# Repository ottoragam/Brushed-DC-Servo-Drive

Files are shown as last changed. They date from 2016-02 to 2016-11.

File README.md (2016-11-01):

# Brushed-DC-Servo-Drive
Low cost servo drive for small CNC machinery

##New version available on https://github.com/ottoragam/Tarocco

----------------------------------------------------------------------
Brushed DC Servo Drive (c) by Gino Magarotto

Brushed DC Servo Drive is licensed under a
Creative Commons Attribution-ShareAlike 3.0 Unported License.

You should have received a copy of the license along with this
work.  If not, see <http://creativecommons.org/licenses/by-sa/3.0/>.

----------------------------------------------------------------------
Low cost servo drive for small CNC machinery

Project log on https://hackaday.io/project/9433-brushed-dc-servo-drive

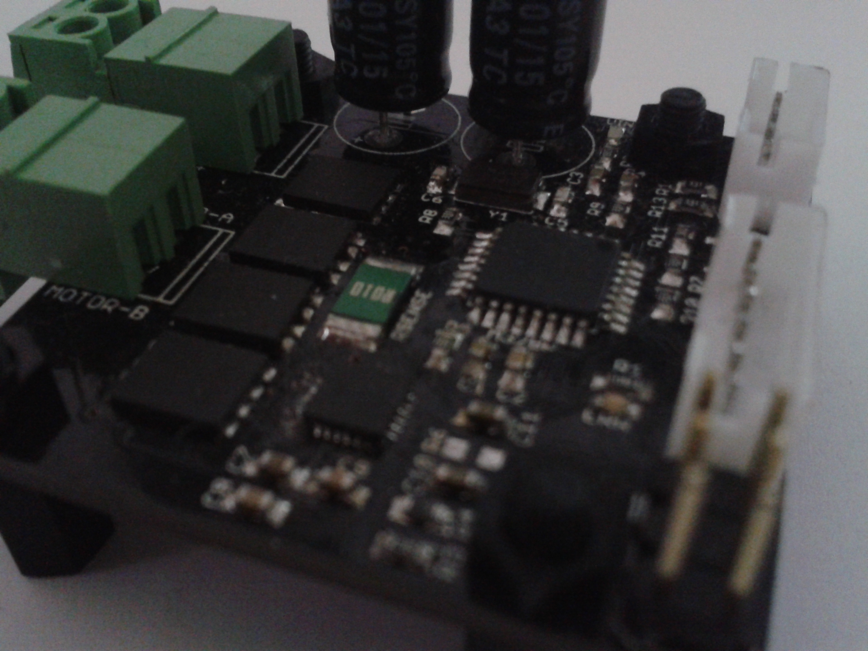
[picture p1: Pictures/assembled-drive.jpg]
drive


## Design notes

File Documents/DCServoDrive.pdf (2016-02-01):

# DC Servo Drive

Low cost closed loop controller for brushed DC motors.

# Safety Information

You should read this notes before installing this device.

CNC equipment can cause injuries due to the forces and momentum involved when the equipment is functioning. One may think that fingers and hands can be replaced with awesome robotic limbs, but they’re very time consuming to install and operate, so you better take care of your original parts.

This device is capable of operating up to 36 VDC and 7 A. The user needs to mind power supply polarity, as the device does not posses reverse polarity protection for any of the power inputs.

Be careful when close to the device while in operation, it may get very hot.

Disconnecting the motor from this device when powered is not advised, as it could damage it.

# Features

This device is designed to control brushed DC motors up to 36 V and 7 A ( HP) for ⅓ positioning in CNC machines such as routers, mills and 3D printers. It could also be used as the power stage of a mobile robot that requires odometry.

The device main components are:

## MCU for closed loop control

An ATmega328 microcontroller operating at 20 MHz is present to read the STEP/DIR signals from the machine controller, read a quadrature encoder input and perform the calculations required for PID control of the motor position.

It also controls an indicator LED for signaling the different fault modes the device is able to detect, such as motor overcurrent and driver undervoltage.

## MOSFET driver

A DRV8701 full bridge mosfet driver provides the capabilities to drive the MOSFET gates at an appropriate voltage with acceptable switching speed, while also protecting them from being damaged from heating due to insufficient gate voltage, shoot-through, etc.

The IC also provides a low side current sense amplifier that uses an external 10 mOhm power resistor to produce a voltage drop across it for the amplifier. The MCU reads the amplified voltage signal (gain is 20) easily with an 8-bit ADC.

Finally, the driver also performs a current limiting function to avoid damaging the transistors. The current level is set via two resistors in a voltage divider configuration.

## MOSFETs in H bridge configuration

The device utilizes four IRFH7545 MOSFETs. This transistors have a breakdown voltage of 60 V and a RDSon of 4.3 mOhm typically (or up to about 9.5 mOhm at 150 °C Tj) with a Vgs of 10 V.

# Device Characteristics

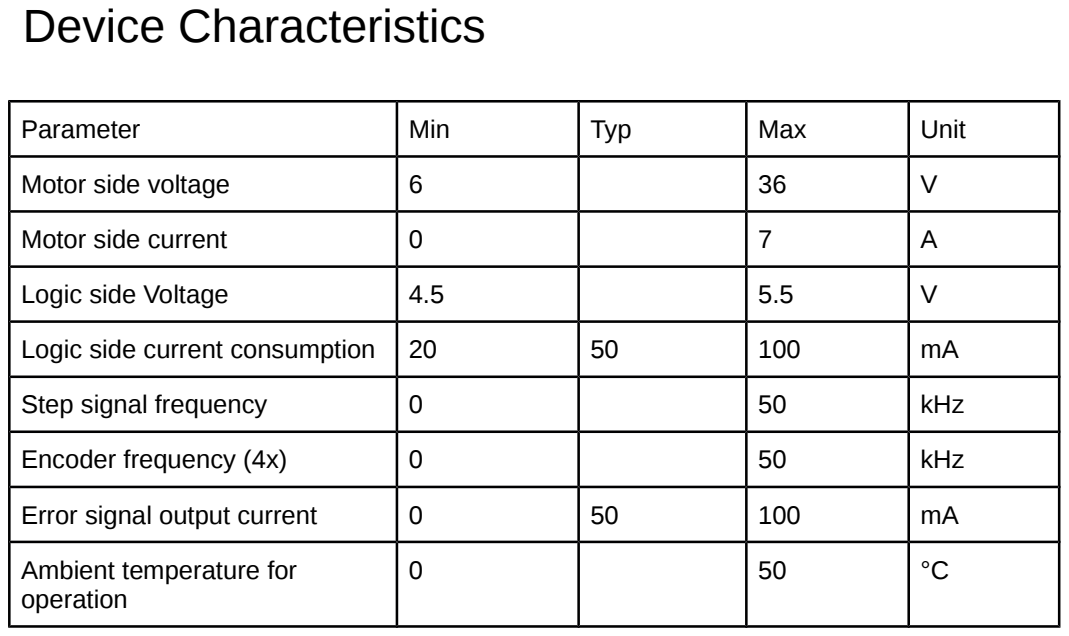
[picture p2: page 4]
Parameter; Min; Typ; Max; Unit; Motor side voltage; Motor side current; Logic side Voltage; Logic side current consumption 20; Step signal frequency; kHz; Encoder frequency (4x); Error signal output current

Ambient temperature for
operation

# Installation

The device comes with two pluggable terminals installed. The one marked with the MOTOR-A and MOTOR-B labels should be connected to the two cables for powering your motor. The other terminal, marked V+ and V- should be connected to a power supply of the correct voltage, ensuring the correct polarity of the connection.

Two JST PH headers are also installed on the board. the 4 way PH header accepts the encoder signal inputs and supplies 5 V to said encoder. The 6 way PH header is used for supplying 5 V to the board’s logic side, accepts the STEP, DIR and RESET signal from the machine controller and has the open drain ERROR output to inform the rest of the system of a fault condition.

The last connector present is a 3x2 0.1 in pitch male header. It is used for reprogramming the MCU present on the board.

Every microcontroller input present in the PH headers has a 330 Ohm resistor connected in series for protection against a mistake when making the connections or a misconfiguration of the pin in the case of a firmware change.

The input signals are active low.

Operation

Troubleshooting

Software Parameters

Electrical Schematic

Dimensional Drawing

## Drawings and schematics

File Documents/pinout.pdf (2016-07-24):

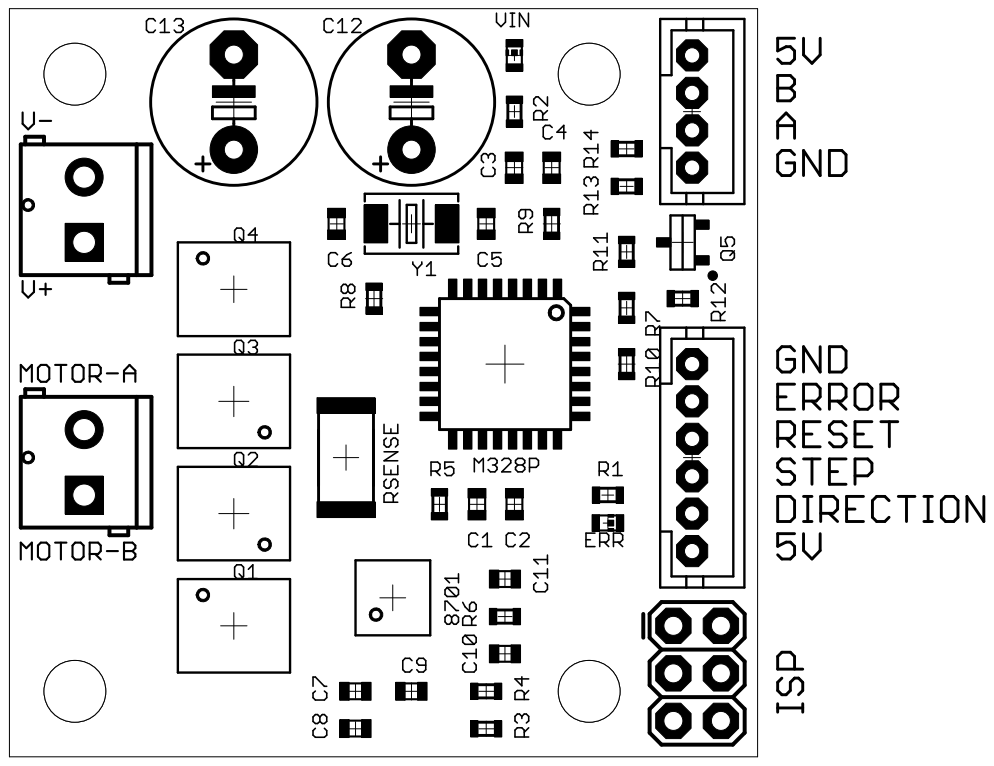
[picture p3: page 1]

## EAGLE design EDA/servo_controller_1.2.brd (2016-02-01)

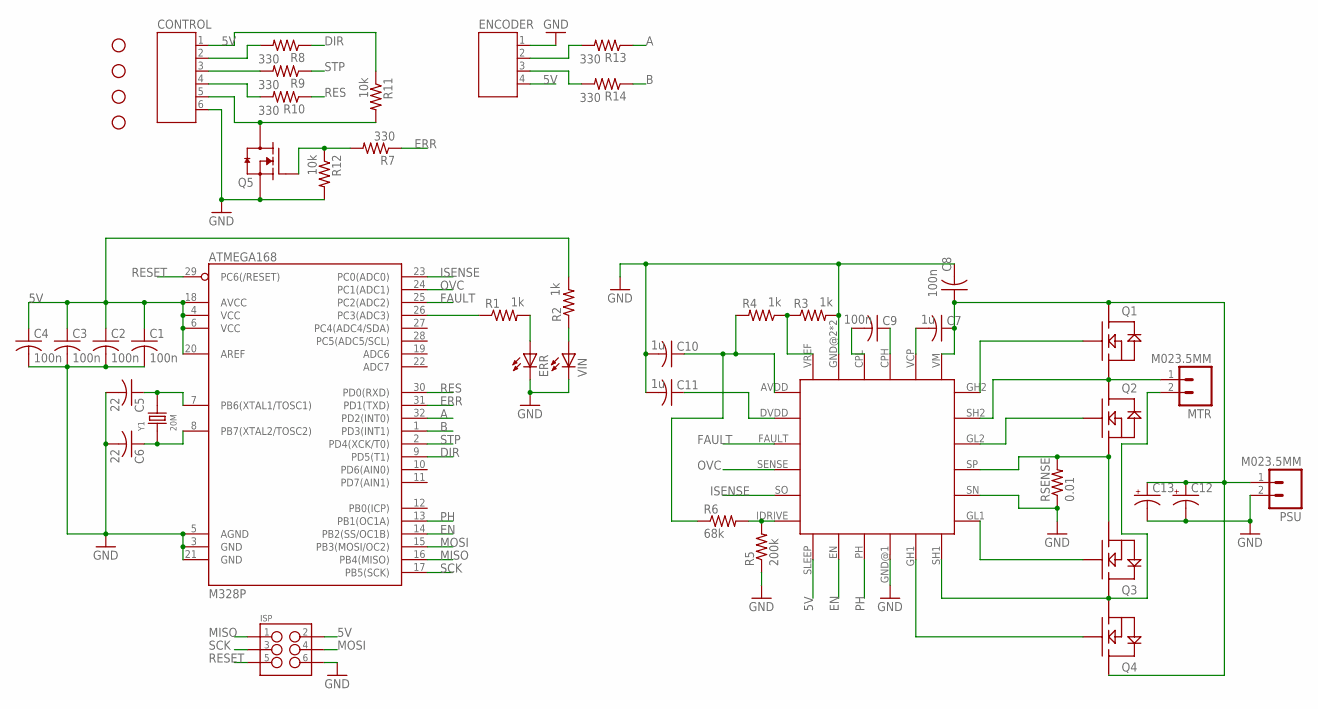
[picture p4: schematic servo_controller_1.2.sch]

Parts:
8701: DRV8701; VQFN24
C1, C2, C3, C4, C8, C9: 100n; C0603
C5, C6: 22; C0603
C7, C10, C11: 1u; C0603
C12, C13: CPOL-USE5-8.5; E5-8,5
CONTROL: JST-PH6
ENCODER: JST-PH4
ERR: LEDCHIP-LED0603; CHIP-LED0603
ISP: M03X22X3_SILK_SM; 2X3
M328P: ATMEGA168; TQFP32-08
MTR: M023.5MM; SCREWTERMINAL-3.5MM-2
PSU: M023.5MM; SCREWTERMINAL-3.5MM-2
Q1, Q2, Q3, Q4: NEXFET_SINGLECSD18537NQ5A; SON5X6
Q5: MOSFET-NCH_SOT-23; SOT95P280X135-3N
R1, R2, R3, R4: 1k; R0603
R5: 200k; R0603
R6: 68k; R0603
R7, R8, R9, R10, R13, R14: 330; R0603
R11, R12: 10k; R0603
RSENSE: 0.01; R2512
STANDOFF1, STANDOFF2, STANDOFF3, STANDOFF4: STAND-OFF
VIN: LEDCHIP-LED0603; CHIP-LED0603
Y1: 20M; X2-SMD-5.0X3.2X1.3MM

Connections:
5V: 8701.SLEEP, C1.1, C2.1, C3.1, C4.1, CONTROL.1, ENCODER.4, ISP.2, M328P.4 (VCC), M328P.6 (VCC), M328P.18 (AVCC), M328P.20 (AREF), R2.2, R11.1
A: M328P.32 (PD2(INT0)), R13.1
B: M328P.1 (PD3(INT1)), R14.1
DIR: M328P.9 (PD5(T1)), R8.1
EN: 8701.EN, M328P.14 (PB2(SS/OC1B))
ERR: M328P.31 (PD1(TXD)), R7.1
FAULT: 8701.FAULT, M328P.25 (PC2(ADC2))
GND: 8701.GND@1 (GND), 8701.GND@2 (GND), 8701.GND@3 (GND), 8701.SN, C1.2, C2.2, C3.2, C4.2, C5.2, C6.2, C8.2, C10.2, C11.2, C12.-, C13.-, CONTROL.6, ENCODER.1, ERR.C, ISP.6, M328P.3 (GND), M328P.5 (AGND), M328P.21 (GND), PSU.2, Q5.2 (S), R3.2, R5.1, R12.2, RSENSE.1, VIN.C
ISENSE: 8701.SO, M328P.23 (PC0(ADC0))
MISO: ISP.1, M328P.16 (PB4(MISO))
MOSI: ISP.4, M328P.15 (PB3(MOSI/OC2))
unnamed: 8701.GL1, Q3.GATE
unnamed: 8701.SH1, MTR.2, Q3.DRAIN@1 (DRAIN), Q3.DRAIN@2 (DRAIN), Q3.DRAIN@3 (DRAIN), Q3.DRAIN@4 (DRAIN), Q3.DRAIN@5 (DRAIN), Q4.SOURCE@1 (SOURCE), Q4.SOURCE@2 (SOURCE), Q4.SOURCE@3 (SOURCE)
unnamed: 8701.SH2, MTR.1, Q1.SOURCE@1 (SOURCE), Q1.SOURCE@2 (SOURCE), Q1.SOURCE@3 (SOURCE), Q2.DRAIN@1 (DRAIN), Q2.DRAIN@2 (DRAIN), Q2.DRAIN@3 (DRAIN), Q2.DRAIN@4 (DRAIN), Q2.DRAIN@5 (DRAIN)
unnamed: 8701.GH2, Q1.GATE
unnamed: 8701.SP, Q2.SOURCE@1 (SOURCE), Q2.SOURCE@2 (SOURCE), Q2.SOURCE@3 (SOURCE), Q3.SOURCE@1 (SOURCE), Q3.SOURCE@2 (SOURCE), Q3.SOURCE@3 (SOURCE), RSENSE.2
unnamed: 8701.GL2, Q2.GATE
unnamed: 8701.GH1, Q4.GATE
unnamed: R2.1, VIN.A
unnamed: C5.1, M328P.7 (PB6(XTAL1/TOSC1)), Y1.2
unnamed: ENCODER.2, R13.2
unnamed: 8701.VCP, C7.2
unnamed: 8701.CPL, C9.2
unnamed: 8701.CPH, C9.1
unnamed: ENCODER.3, R14.2
unnamed: 8701.VREF, R3.1, R4.1
unnamed: 8701.AVDD, C10.1, R4.2, R6.1
unnamed: 8701.DVDD, C11.1
unnamed: C6.1, M328P.8 (PB7(XTAL2/TOSC2)), Y1.1
unnamed: ERR.A, R1.2
unnamed: Q5.1 (G), R7.2, R12.1
unnamed: 8701.IDRIVE, R5.2, R6.2
unnamed: 8701.VM, C7.1, C8.1, C12.+, C13.+, PSU.1, Q1.DRAIN@1 (DRAIN), Q1.DRAIN@2 (DRAIN), Q1.DRAIN@3 (DRAIN), Q1.DRAIN@4 (DRAIN), Q1.DRAIN@5 (DRAIN), Q4.DRAIN@1 (DRAIN), Q4.DRAIN@2 (DRAIN), Q4.DRAIN@3 (DRAIN), Q4.DRAIN@4 (DRAIN), Q4.DRAIN@5 (DRAIN)
unnamed: M328P.26 (PC3(ADC3)), R1.1
unnamed: CONTROL.2, R8.2
unnamed: CONTROL.3, R9.2
unnamed: CONTROL.4, R10.2
unnamed: CONTROL.5, Q5.3 (D), R11.2
OVC: 8701.SENSE, M328P.24 (PC1(ADC1))
PH: 8701.PH, M328P.13 (PB1(OC1A))
RES: M328P.30 (PD0(RXD)), R10.1
RESET: ISP.5, M328P.29 (PC6(/RESET))
SCK: ISP.3, M328P.17 (PB5(SCK))
STP: M328P.2 (PD4(XCK/T0)), R9.1

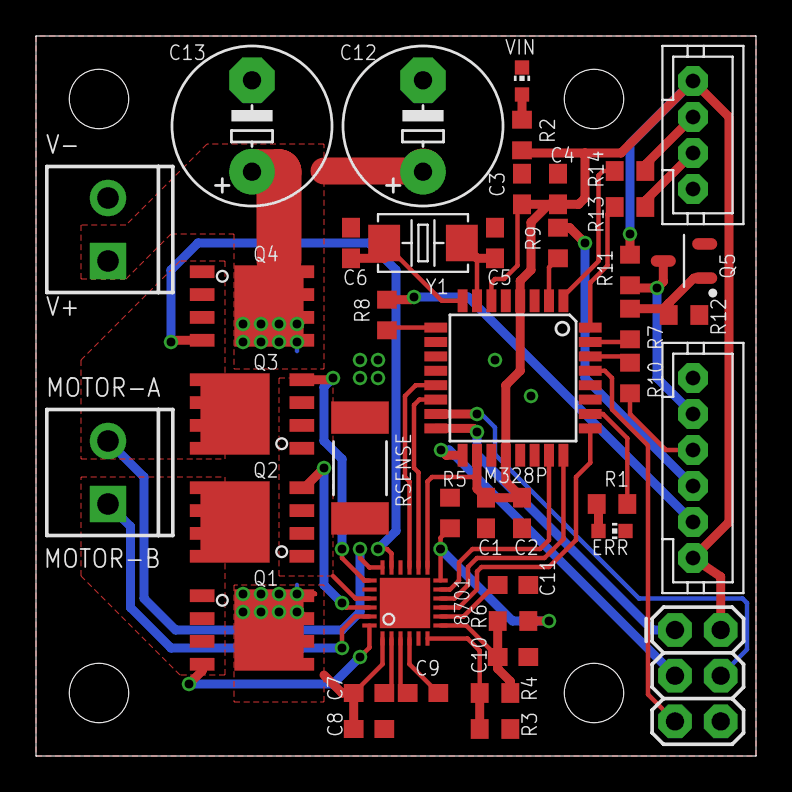
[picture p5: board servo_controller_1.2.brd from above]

Board: 2 copper layers, 40.0 x 40.0 mm, 47 parts (0 on the bottom side), 44 nets.

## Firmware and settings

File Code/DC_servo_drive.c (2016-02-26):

/*
 */

#include <avr/io.h>
#include <avr/interrupt.h>
#include <util/atomic.h>

#define CONTROL_OUTPUT_SHIFT    9
#define ADC_SAMPLES             8192
#define ADC_AVERAGE_SHIFT       13

#define PWM_OUTPUT_MAX          1023
#define CURRENT_MAX             5
#define ERROR_INTEGRAL_MAX      32000
#define SET_POINT_MULTIPLIER    1
#define PID_TIMER_COUNTS        5
#define FOLLOWING_ERROR         35
#define ENCODER_FAULT           60000

#define ROTATE_CCW              PORTB|=(1<<1)
#define ROTATE_CW               PORTB&=~(1<<1)

#define SET_ERR_LED             PORTC|=(1<<3)
#define CLEAR_ERR_LED           PORTC&=~(1<<3)
#define SET_ERR_OUTPUT          PORTD|=(1<<1)
#define CLEAR_ERR_OUTPUT        PORTD&=~(1<<1)
#define PULLUP_RES              PORTD|=(1<<0);
#define PULLUP_A                PORTD|=(1<<2);
#define PULLUP_B                PORTD|=(1<<3);
#define PULLUP_STP              PORTD|=(1<<4);
#define PULLUP_DIR              PORTD|=(1<<5);
#define DUTY_CYCLE              OCR1B
#define PID_SAMPLING_TIME       OCR0A

volatile uint8_t new_step, encoder_state, encoder_state_prev;
volatile uint8_t fault_condition, keep_reset;
volatile int16_t error, error_prev, error_integral, error_derivative;
volatile uint16_t adc_value, adc_samples_counter;

int main(void) {

    uint8_t adc_average=0;
    uint16_t encoder_not_changing=0;
    uint16_t Kp=3000, Ki=1, Kd=0;
    uint16_t pwm_output=0;
    int32_t control_output=0;

    DDRB|=(1<<1)|(1<<2);                                                        //PH/EN output
    DDRC|=(1<<3);                                                               //ERR LED output
    PORTC|=(1<<1)|(1<<2);                                                       //OVC/FAULT pull ups
    DDRD|=(1<<1);                                                               //ERR output

    PULLUP_RES;
    PULLUP_STP;
    PULLUP_DIR;

    TCCR1A|=(1<<WGM11)|(1<<WGM10)|(1<<COM1B1);	                                //Phase correct PWM 10-bit non inverting mode
    TCCR1B|=(1<<CS10);	                                                        //Set prescaler 1, PWM freq 10 kHz

    TCCR0A|=(1<<WGM01);                                                         //CTC mode, set prescaler 1024
    TCCR0B|=(1<<CS02)|(1<<CS00);
    TIMSK0|=(1<<OCIE0A);

    PID_SAMPLING_TIME=PID_TIMER_COUNTS;                                         //Each timer count amounts to 51.2 us, so 5 is 256 us

    TCCR2A|=(1<<WGM21);                                                         //CTC mode, set prescaler 1024
    TCCR2B|=(1<<CS22)|(1<<CS20);
    TIMSK0|=(1<<OCIE0A);

    ADMUX|=(1<<ADLAR);                                                          //AREF, 8-bit conversion, channel 0
    ADCSRA|=(1<<ADEN)|(1<<ADSC)|(1<<ADATE)|(1<<ADIE)|(1<<ADPS2)|(1<<ADPS0);     //Auto trigger, ADC interrupts, 625 kHz clock

    EICRA|=(1<<ISC10)|(1<<ISC00);                                               //enable A/B interrupts (any edge)
    EIMSK|=(1<<INT1)|(1<<INT0);

    PCICR|=(1<<PCIE2);                                                          //enable STP interrupt
    PCMSK2|=(1<<PCINT20);

    if(PIND&(1<<2)) encoder_state|=(1<<0);                                      //zero encoder_state/encoder_state_prev
    else encoder_state&=~(1<<0);
    if(PIND&(1<<3)) encoder_state|=(1<<1);
    else encoder_state&=~(1<<1);
    encoder_state_prev=encoder_state;

    sei();

    while(1) {

        ATOMIC_BLOCK(ATOMIC_FORCEON) {
            //9.8 us
            control_output=((int32_t)Kp*error)+((int32_t)Ki*error_integral)-((int32_t)Kd*error_derivative);
        }
        if(control_output>0) {
            ROTATE_CW;
        }
        else if(control_output<0) {
            ROTATE_CCW;
            control_output*=-1;
        }
        //3.4 us
        pwm_output=(uint16_t)(control_output>>CONTROL_OUTPUT_SHIFT);
        if(pwm_output>PWM_OUTPUT_MAX) pwm_output=PWM_OUTPUT_MAX;

        /*
        if((PIND&(1<<0))==0) {                                                                  //RES pin low
            fault_condition|=(1<<0);
        }
        else fault_condition=0;                                                                 //RES pin HIGH
        if((PINC&(1<<2))==0) fault_condition|=(1<<1);                                           //driver FAULT
        ATOMIC_BLOCK(ATOMIC_FORCEON) {
            //0.7 us
            if(adc_samples_counter==ADC_SAMPLES) {
                adc_average=(uint8_t)(adc_value>>ADC_AVERAGE_SHIFT);
                adc_value=0;
                adc_samples_counter=0;
            }
        }
        if(adc_average>CURRENT_MAX) fault_condition|=(1<<3);                                    //overcurrent
        */

        if(new_step==1) {
            fault_condition=0;
            new_step=0;
        }

        if(error>FOLLOWING_ERROR || error<-1*FOLLOWING_ERROR) {
            keep_reset=1;
            SET_ERR_LED;
        }
        else {
            if(encoder_state!=encoder_state_prev) {
                encoder_not_changing=0;
            }
            else {
                encoder_not_changing++;
                if(encoder_not_changing==ENCODER_FAULT) {
                    fault_condition=1;
                    encoder_not_changing=0;
                }
            }
        }
        if(keep_reset==0) {
            if(fault_condition==0) DUTY_CYCLE=pwm_output;
            else if(fault_condition==1) DUTY_CYCLE=0;
        }
        else {
            DUTY_CYCLE=0;
            error=0;
            error_prev=0;
            error_integral=0;
            error_derivative=0;
        }

    }

    return 0;
}

ISR(INT0_vect) {                                                                //encoder A
    //2.4us
    if(PIND&(1<<2)) encoder_state|=(1<<0);
    else encoder_state&=~(1<<0);

    switch(encoder_state) {
    case 0:
        //if(encoder_state_prev==2) error++;
        if(encoder_state_prev==1) error--;
        //else if(encoder_state_prev==0) ;
        else SET_ERR_LED;
        encoder_state_prev=0;
        break;
    case 1:
        if(encoder_state_prev==0) error++;
        //if(encoder_state_prev==3) error--;
        //else if(encoder_state_prev==1) ;
        else SET_ERR_LED;
        encoder_state_prev=1;
        break;
    case 3:
        //if(encoder_state_prev==1) error++;
        if(encoder_state_prev==2) error--;
        //else if(encoder_state_prev==3) ;
        else SET_ERR_LED;
        encoder_state_prev=3;
        break;
    case 2:
        if(encoder_state_prev==3) error++;
        //if(encoder_state_prev==0) error--;
        //else if(encoder_state_prev==2) ;
        else SET_ERR_LED;
        encoder_state_prev=2;
        break;
    }
}

ISR(INT1_vect) {                                                                //encoder B
    //2.4 us
    if(PIND&(1<<3)) encoder_state|=(1<<1);
    else encoder_state&=~(1<<1);

    switch(encoder_state) {
    case 0:
        if(encoder_state_prev==2) error++;
        //if(encoder_state_prev==1) error--;
        //else if(encoder_state_prev==0) ;
        else SET_ERR_LED;
        encoder_state_prev=0;
        break;
    case 1:
        //if(encoder_state_prev==0) error++;
        if(encoder_state_prev==3) error--;
        //else if(encoder_state_prev==1) ;
        else SET_ERR_LED;
        encoder_state_prev=1;
        break;
    case 3:
        if(encoder_state_prev==1) error++;
        //if(encoder_state_prev==2) error--;
        //else if(encoder_state_prev==3) ;
        else SET_ERR_LED;
        encoder_state_prev=3;
        break;
    case 2:
        //if(encoder_state_prev==3) error++;
        if(encoder_state_prev==0) error--;
        //else if(encoder_state_prev==2) ;
        else SET_ERR_LED;
        encoder_state_prev=2;
        break;
    }
}

ISR(PCINT2_vect) {                                                              //input STEP
    //1.75 us
    new_step=1;
    if((PIND&(1<<4))==0) {                                                      //check for low pulse
        if(PIND&(1<<5)) {                                                       //check DIR
            error+=SET_POINT_MULTIPLIER;
            error_prev+=SET_POINT_MULTIPLIER;
        }
        else {
            error-=SET_POINT_MULTIPLIER;
            error_prev-=SET_POINT_MULTIPLIER;
        }
    }
}

ISR(TIMER0_COMPA_vect) {
    //2.7 us
    error_integral+=error;
    if(error_integral>ERROR_INTEGRAL_MAX) error_integral=ERROR_INTEGRAL_MAX;
    else if(error_integral<-ERROR_INTEGRAL_MAX) error_integral=-ERROR_INTEGRAL_MAX;
    error_derivative=error_prev-error;
    error_prev=error;
}

ISR(ADC_vect) {
    //1.2 us
    adc_value+=ADCH;
    adc_samples_counter++;
}

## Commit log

2016-02-01 Eagle files
    [servo_controller_1.2.brd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]
2016-02-19 removed incorrect BOM file
2016-02-26 added encoder fault detection
2016-07-24 pinout diagram for the board

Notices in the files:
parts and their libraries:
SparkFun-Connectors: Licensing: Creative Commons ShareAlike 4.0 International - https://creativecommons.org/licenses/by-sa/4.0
